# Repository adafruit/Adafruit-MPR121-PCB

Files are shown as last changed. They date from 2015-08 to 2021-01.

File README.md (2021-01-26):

## Adafruit MPR121 capacitive touch breakout PCB
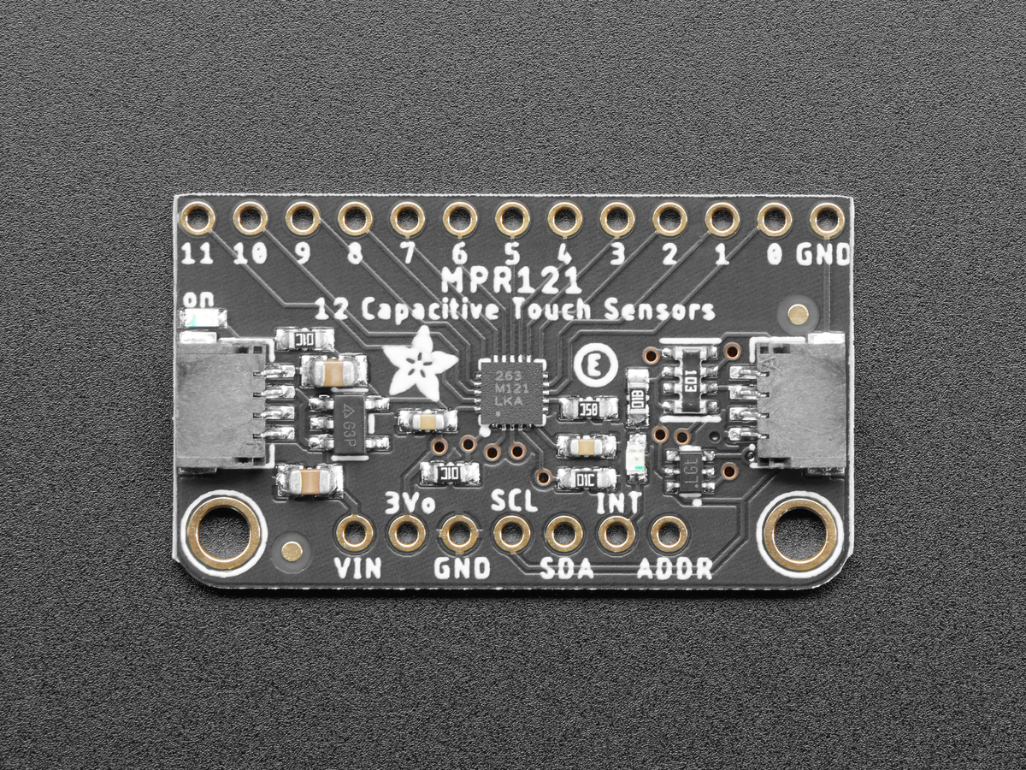
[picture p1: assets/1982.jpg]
<a href="http://www.adafruit.com/products/1982"><br/>
Click here to purchase one from the Adafruit shop</a>
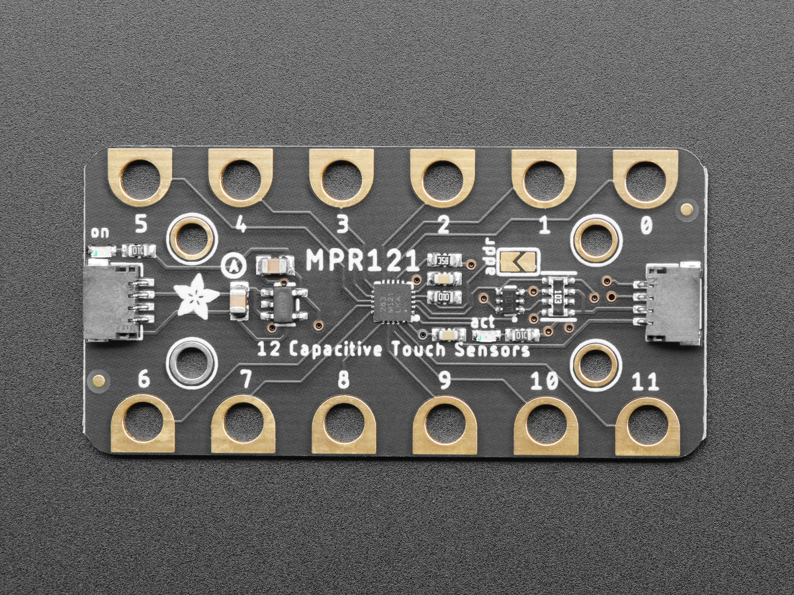
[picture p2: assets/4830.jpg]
<a href="http://www.adafruit.com/products/4830"><br/>
Click here to purchase one from the Adafruit shop</a>

Add lots of touch sensors to your next microcontroller project with this easy-to-use 12-channel capacitive touch sensor breakout board, starring the MPR121. This chip can handle up to 12 individual touch pads.

The MPR121 has support for only I2C, which can be implemented with nearly any microcontroller. You can select one of 4 addresses with the ADDR pin (or two on the Gator version), for a total of 48 (24 on the Gator version) capacitive touch pads on one I2C 2-wire bus. Using this chip is a lot easier than doing the capacitive sensing with analog inputs: it handles all the filtering for you and can be configured for more/less sensitivity.

This sensor comes as a tiny hard-to-solder chip so we put it onto a breakout board for you. Since it's a 3V-only chip, we added a 3V regulator and I2C level shifting so its safe to use with any 3V or 5V microcontroller/processor like Arduino. We even added an LED onto the IRQ line so it will blink when touches are detected, making debugging by sight a bit easier on you. Comes with a fully assembled board, and a stick of 0.1" header so you can plug it into a breadboard. For contacts, we suggest using copper foil or pyralux, then solder a wire that connects from the foil pad to the breakout.

To make using the MPR121 QT Gator as easy as possible, we’ve put the MPR121 on a breakout PCB in our Stemma QT form factor with a sprinkle of support circuitry to give you options when testing. You can either use a breadboard or the SparkFun qwiic compatible STEMMA QT connectors, and compatibility with 5V voltage levels as commonly found on Arduinos, as well as 3.3V logic used by many other boards like the Raspberry Pi or our Feathers. QT Cable is not included, but we have a variety in the shop for quick plug-and-play support.

PCB files for Adafruit MPR121 capacitive touch breakout. The format is EagleCAD schematic and board layout
- https://www.adafruit.com/product/1982
- https://www.adafruit.com/product/4830

### License

Adafruit invests time and resources providing this open source design, please support Adafruit and open-source hardware by purchasing products from [Adafruit](https://www.adafruit.com)!

All text above must be included in any redistribution

Designed by Limor Fried/Ladyada for Adafruit Industries.
Creative Commons Attribution/Share-Alike, all text above must be included in any redistribution.
See license.txt for additional information.

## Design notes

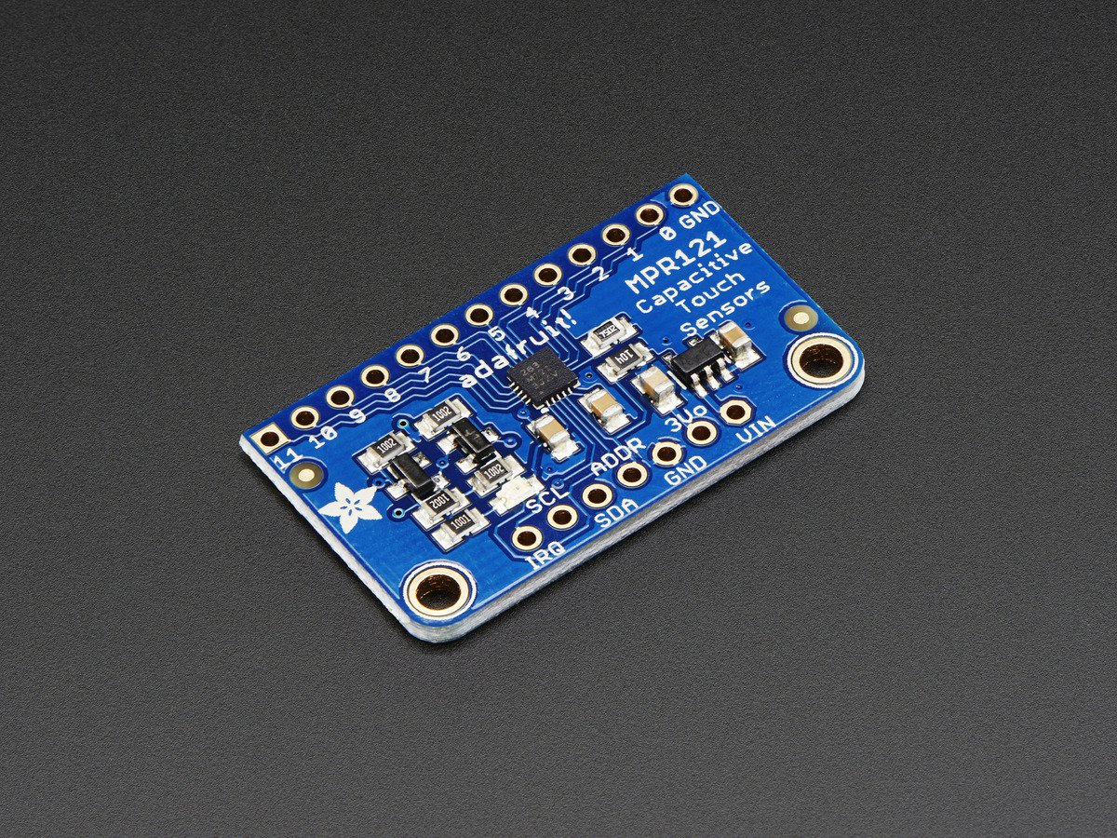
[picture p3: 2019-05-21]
assets/image.jpg

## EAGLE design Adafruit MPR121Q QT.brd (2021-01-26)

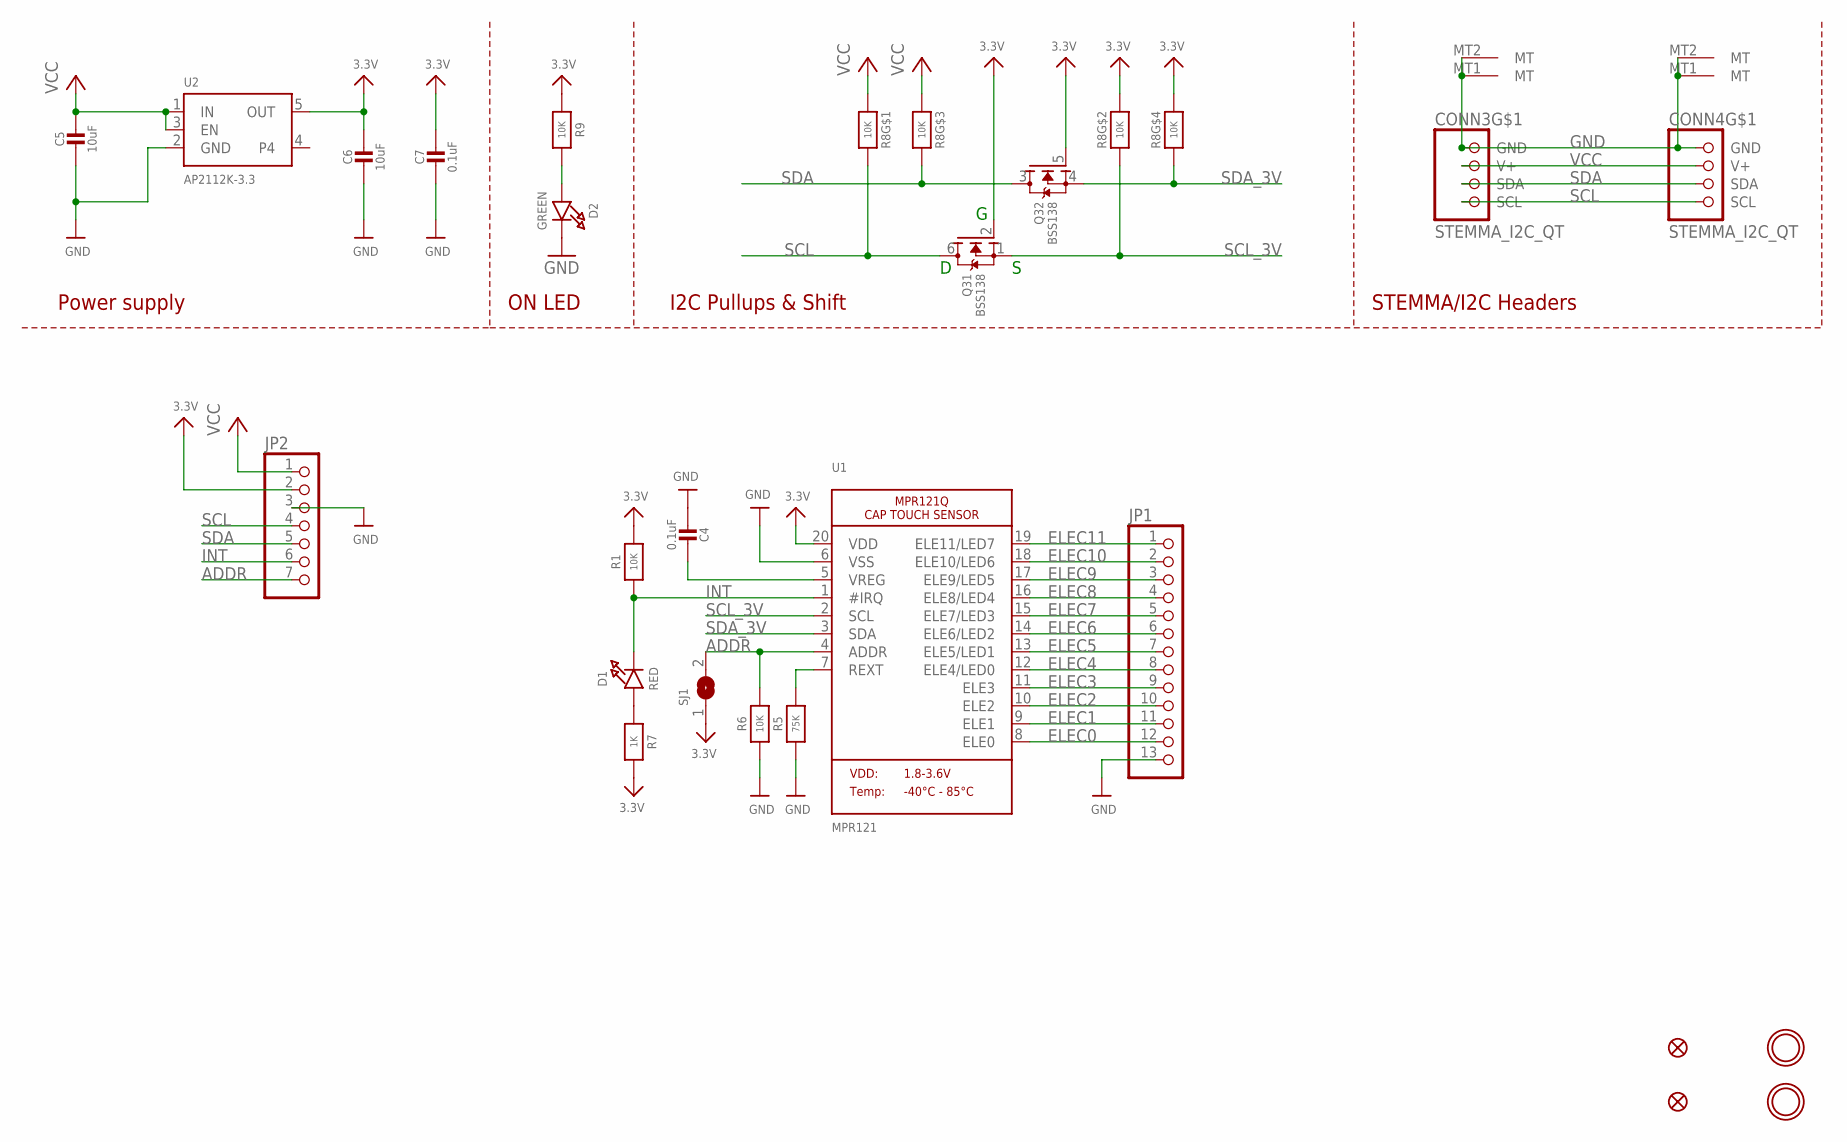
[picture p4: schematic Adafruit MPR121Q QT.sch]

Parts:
C4, C7: 0.1uF; 0603-NO
C5, C6: 10uF; 0805-NO
CONN3, CONN4: STEMMA_I2C_QT; JST_SH4
D1: RED; CHIPLED_0603_NOOUTLINE
D2: GREEN; CHIPLED_0603_NOOUTLINE
FID3, FID4: FIDUCIAL_1MM
JP1: HEADER-1X13; 1X13_ROUND_70
JP2: HEADER-1X770MIL; 1X07_ROUND_70
Q3: BSS138; SOT363
R1, R6, R9: 10K; 0603-NO
R5: 75K; 0603-NO
R7: 1K; 0603-NO
R8: 10K; RESPACK_4X0603
SJ1: SOLDERJUMPER; SOLDERJUMPER_ARROW_NOPASTE
U1: MPR121; QFN20_3MM_NOTHERMAL
U2: AP2112K-3.3; SOT23-5
U$34, U$35: MOUNTINGHOLE2.5; MOUNTINGHOLE_2.5_PLATED

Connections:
3.3V: C6.1, C7.1, JP2.2, Q3.2 (G), Q3.5 (G), R1.2, R7.2, R8.2 (1), R8.4 (1), R9.1, SJ1.1, U1.20 (VDD), U2.5 (OUT)
ADDR: JP2.7, R6.2, SJ1.2, U1.4 (ADDR)
ELEC0: JP1.12, U1.8 (ELE0)
ELEC1: JP1.11, U1.9 (ELE1)
ELEC2: JP1.10, U1.10 (ELE2)
ELEC3: JP1.9, U1.11 (ELE3)
ELEC4: JP1.8, U1.12 (ELE4/LED0)
ELEC5: JP1.7, U1.13 (ELE5/LED1)
ELEC6: JP1.6, U1.14 (ELE6/LED2)
ELEC7: JP1.5, U1.15 (ELE7/LED3)
ELEC8: JP1.4, U1.16 (ELE8/LED4)
ELEC9: JP1.3, U1.17 (ELE9/LED5)
ELEC10: JP1.2, U1.18 (ELE10/LED6)
ELEC11: JP1.1, U1.19 (ELE11/LED7)
GND: C4.2, C5.2, C6.2, C7.2, CONN3.1 (GND), CONN3.MT1 (MT), CONN3.MT2 (MT), CONN4.1 (GND), CONN4.MT1 (MT), CONN4.MT2 (MT), D2.C, JP1.13, JP2.3, R5.1, R6.1, U1.6 (VSS), U2.2 (GND)
INT: D1.C, JP2.6, R1.1, U1.1 (#IRQ)
unnamed: D1.A, R7.1
unnamed: C4.1, U1.5 (VREG)
unnamed: R5.2, U1.7 (REXT)
unnamed: D2.A, R9.2
SCL: CONN3.4 (SCL), CONN4.4 (SCL), JP2.4, Q3.6 (D), R8.8 (2)
SCL_3V: Q3.1 (S), R8.7 (2), U1.2 (SCL)
SDA: CONN3.3 (SDA), CONN4.3 (SDA), JP2.5, Q3.3 (D), R8.6 (2)
SDA_3V: Q3.4 (S), R8.5 (2), U1.3 (SDA)
VCC: C5.1, CONN3.2 (V+), CONN4.2 (V+), JP2.1, R8.1, R8.3 (1), U2.1 (IN), U2.3 (EN)

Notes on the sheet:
I2C Pullups & Shift
STEMMA/I2C Headers
ON LED
Power supply

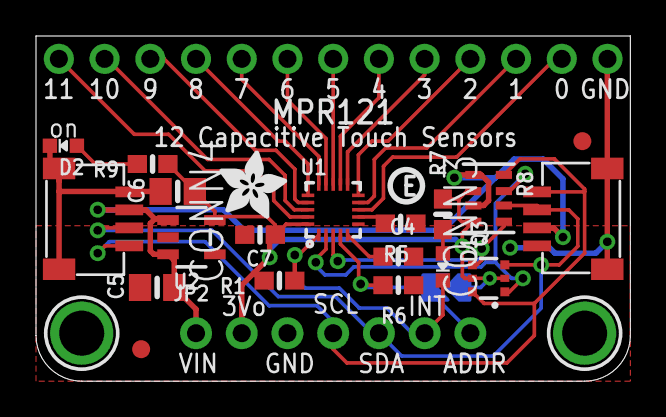
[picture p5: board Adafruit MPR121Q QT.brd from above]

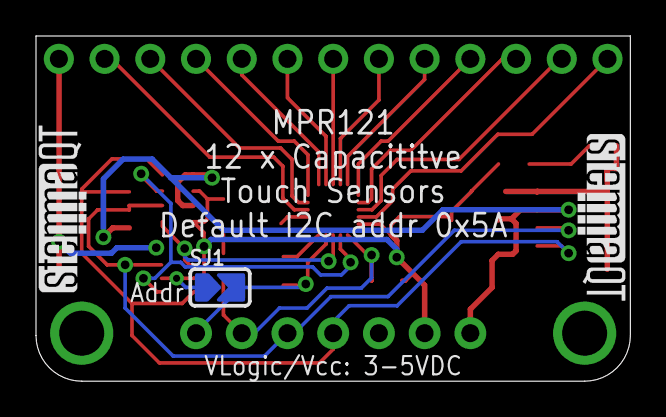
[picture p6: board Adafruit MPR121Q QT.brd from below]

Board: 2 copper layers, 33.0 x 19.2 mm, 28 parts (3 on the bottom side), 25 nets.

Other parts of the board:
U$9: PCBFEAT-REV-040
U$37: ADAFRUIT_3.5MM
U$39, U$40: STEMMAQT

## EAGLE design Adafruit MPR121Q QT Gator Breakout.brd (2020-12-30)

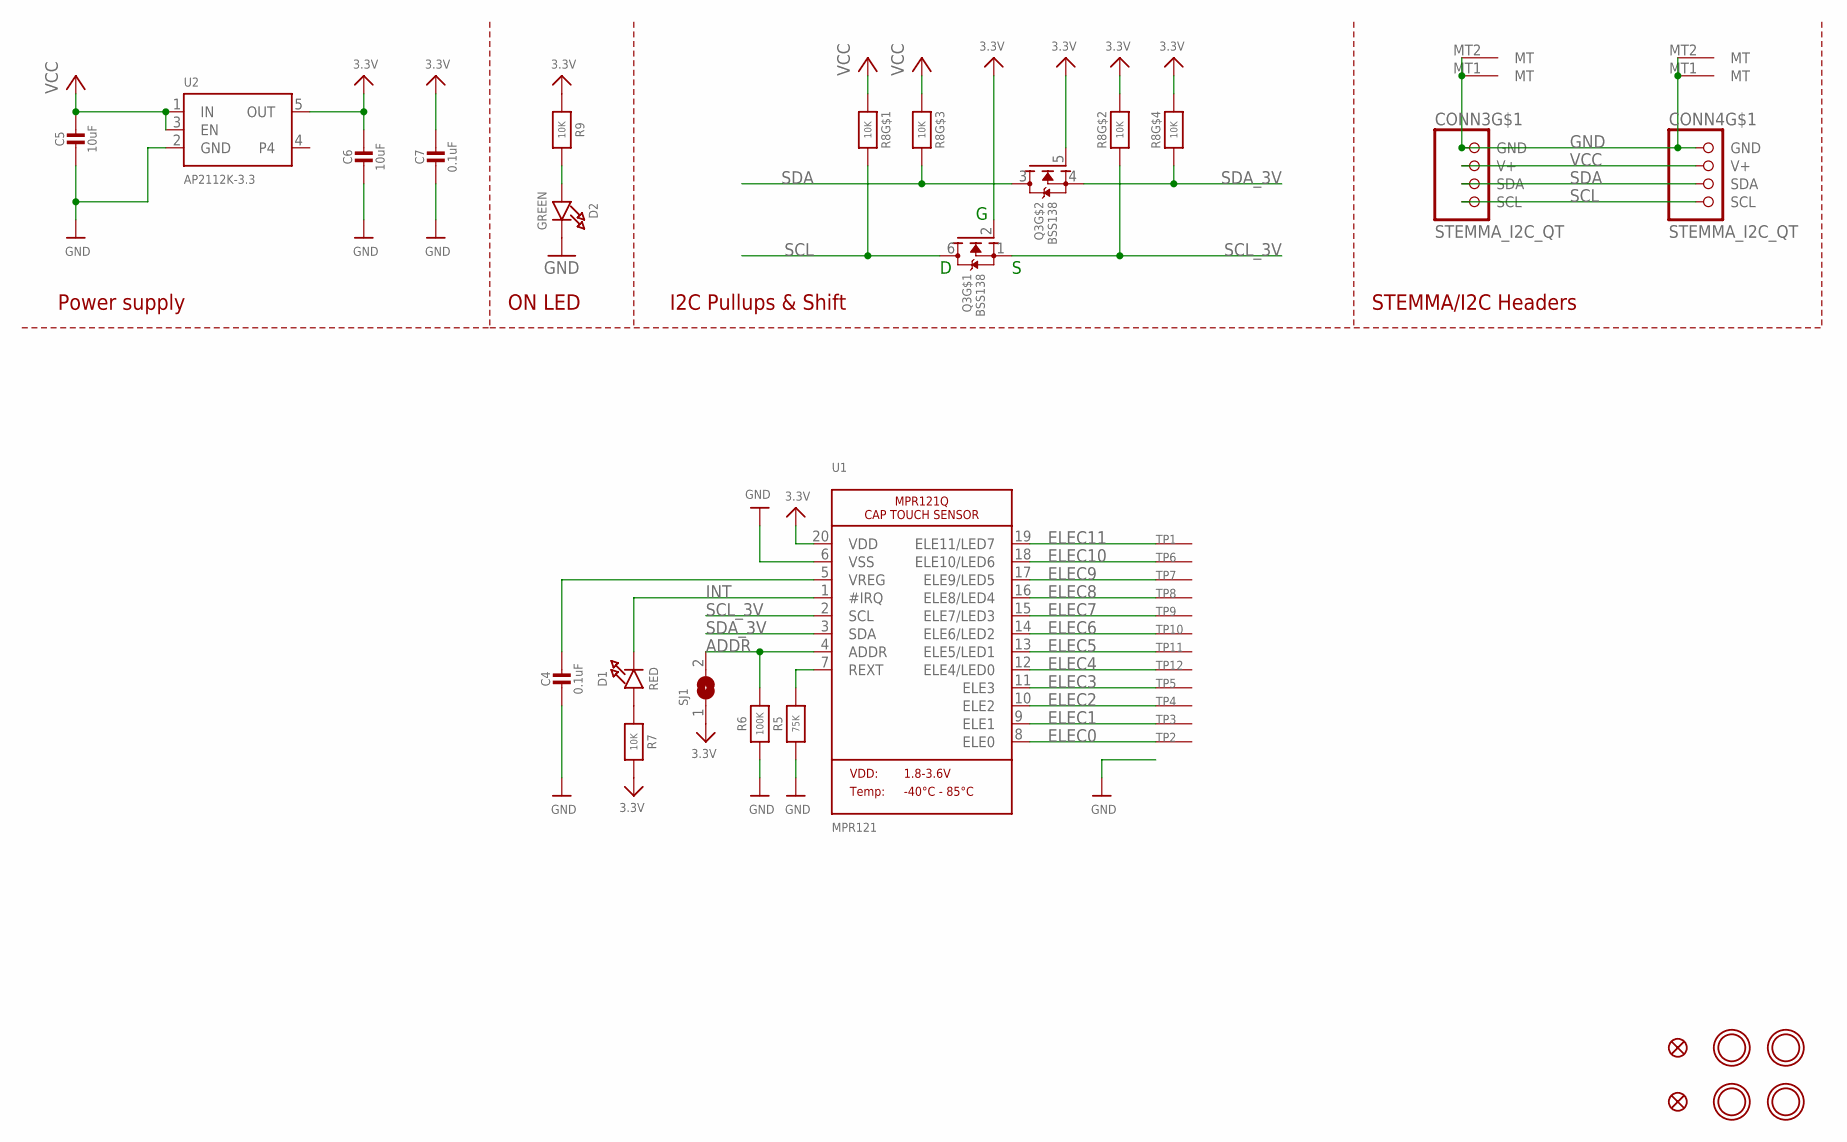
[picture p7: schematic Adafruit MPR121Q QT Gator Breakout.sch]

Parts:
C4, C7: 0.1uF; 0603-NO
C5, C6: 10uF; 0805-NO
CONN3, CONN4: STEMMA_I2C_QT; JST_SH4
D1: RED; CHIPLED_0603_NOOUTLINE
D2: GREEN; CHIPLED_0603_NOOUTLINE
FID3, FID4: FIDUCIAL_1MM
Q3: BSS138; SOT363
R5: 75K; 0603-NO
R6: 100K; 0603-NO
R7, R9: 10K; 0603-NO
R8: 10K; RESPACK_4X0603
SJ1: SOLDERJUMPER; SOLDERJUMPER_ARROW_NOPASTE
TP1, TP2, TP3, TP4, TP5, TP6, TP7, TP8, TP9, TP10, TP11, TP12: SEWTAPPCB_ALLIGATOR; PCB_ALLI
U1: MPR121; QFN20_3MM_NOTHERMAL
U2: AP2112K-3.3; SOT23-5
U$7, U$8, U$34, U$35: MOUNTINGHOLE2.5; MOUNTINGHOLE_2.5_PLATED

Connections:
3.3V: C6.1, C7.1, Q3.2 (G), Q3.5 (G), R7.2, R8.2 (1), R8.4 (1), R9.1, SJ1.1, U1.20 (VDD), U2.5 (OUT)
ADDR: R6.2, SJ1.2, U1.4 (ADDR)
ELEC0: TP2.P$1, U1.8 (ELE0)
ELEC1: TP3.P$1, U1.9 (ELE1)
ELEC2: TP4.P$1, U1.10 (ELE2)
ELEC3: TP5.P$1, U1.11 (ELE3)
ELEC4: TP12.P$1, U1.12 (ELE4/LED0)
ELEC5: TP11.P$1, U1.13 (ELE5/LED1)
ELEC6: TP10.P$1, U1.14 (ELE6/LED2)
ELEC7: TP9.P$1, U1.15 (ELE7/LED3)
ELEC8: TP8.P$1, U1.16 (ELE8/LED4)
ELEC9: TP7.P$1, U1.17 (ELE9/LED5)
ELEC10: TP6.P$1, U1.18 (ELE10/LED6)
ELEC11: TP1.P$1, U1.19 (ELE11/LED7)
GND: C4.2, C5.2, C6.2, C7.2, CONN3.1 (GND), CONN3.MT1 (MT), CONN3.MT2 (MT), CONN4.1 (GND), CONN4.MT1 (MT), CONN4.MT2 (MT), D2.C, R5.1, R6.1, U1.6 (VSS), U2.2 (GND)
INT: D1.C, U1.1 (#IRQ)
unnamed: D1.A, R7.1
unnamed: C4.1, U1.5 (VREG)
unnamed: R5.2, U1.7 (REXT)
unnamed: D2.A, R9.2
SCL: CONN3.4 (SCL), CONN4.4 (SCL), Q3.6 (D), R8.8 (2)
SCL_3V: Q3.1 (S), R8.7 (2), U1.2 (SCL)
SDA: CONN3.3 (SDA), CONN4.3 (SDA), Q3.3 (D), R8.6 (2)
SDA_3V: Q3.4 (S), R8.5 (2), U1.3 (SDA)
VCC: C5.1, CONN3.2 (V+), CONN4.2 (V+), R8.1, R8.3 (1), U2.1 (IN), U2.3 (EN)

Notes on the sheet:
I2C Pullups & Shift
STEMMA/I2C Headers
ON LED
Power supply

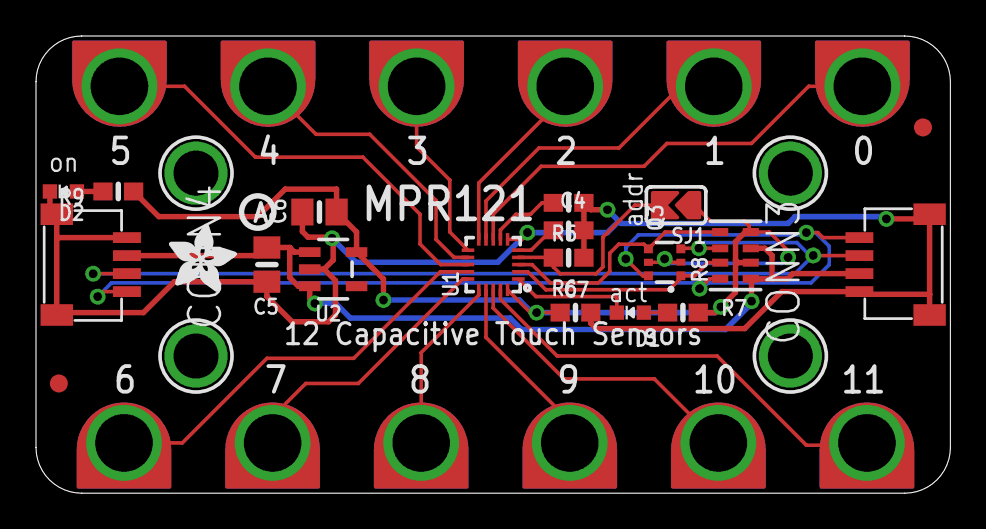
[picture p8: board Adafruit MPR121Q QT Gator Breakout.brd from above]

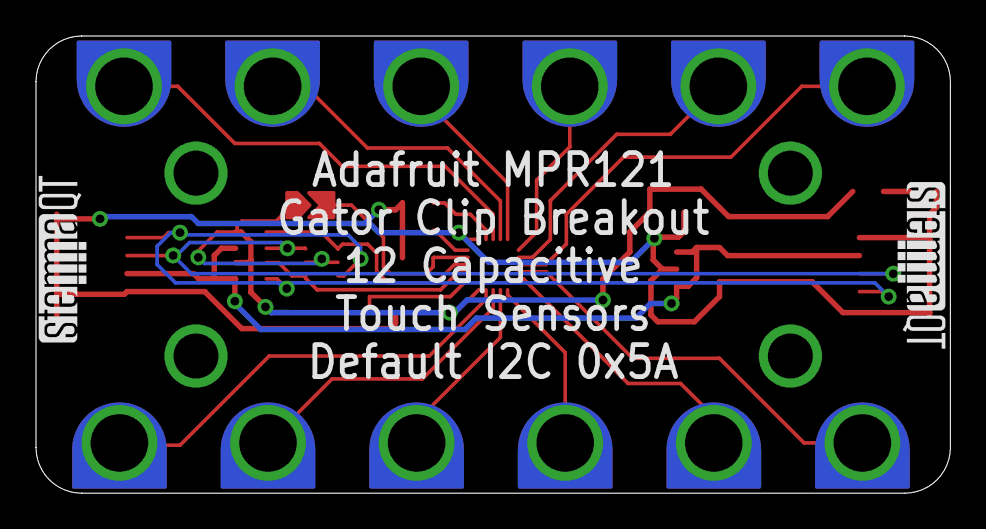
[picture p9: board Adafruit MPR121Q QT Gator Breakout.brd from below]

Board: 2 copper layers, 50.8 x 25.4 mm, 39 parts (2 on the bottom side), 25 nets.

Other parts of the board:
U$10: PCBFEAT-REV-040
U$37: ADAFRUIT_3.5MM
U$39, U$40: STEMMAQT

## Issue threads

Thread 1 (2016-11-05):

Are Q1 and Q2 placed right way?

husztikd, 2016-11-05:
In the schematic, Q1 and Q2 have 3v3 on their gate, sda/scl 3v on source and sda/scl 5v on drain. I think, I think gate and drain should be exchanged for work normally. (5v signals control the mosfet)  Am i right?

Closed 2016-11-05.

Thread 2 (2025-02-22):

STEP files

appsforartists, 2025-02-22:
I am new to Fusion 360.  I was able to import a Pi Pico into my project by uploading the STEP file to my Fusion account and then clicking Import component.

When I try to do the same with these EAGLE CAD files, I end up with an electronics project in Fusion 360, but I cannot figure out how to convert it to a component.  When I search online, I see that I should be able to select "Insert into Current Design" from the context menu, but that doesn't appear for electronics projects.  (It appears for other projects in my data panel.)

It would be helpful if these were available in a more accessible format, like STEP.

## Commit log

2015-08-27 mpr121 breakout
    [Adafruit MPR121 Breakout.brd, Adafruit MPR121 Breakout.sch]
2020-12-30 Adding Gator board files.
    [Adafruit MPR121Q QT Gator Breakout.brd, Adafruit MPR121Q QT Gator Breakout.sch]
2021-01-26 Adding board files.
    [Adafruit MPR121Q QT.brd, Adafruit MPR121Q QT.sch]

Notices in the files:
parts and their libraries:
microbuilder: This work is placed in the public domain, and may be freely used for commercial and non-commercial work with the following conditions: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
